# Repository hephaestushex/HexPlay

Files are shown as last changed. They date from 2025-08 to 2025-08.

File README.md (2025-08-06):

# HexPlay
A handheld gaming console powered by the Raspberry Pi 4/5. This handheld will run Android, using the touchscreen provided by the display. With 2 analog sticks and 15 more inputs, this will be able to play any game upto GameCube (using pi 5) or N64 (using pi 4). The handheld uses a powerbank to provide power to the handheld. This handheld is somewhat cold-swappable, with all connections to the pi is hdmi or usb.

I made this project for several reasons. Number one: points for flight reimbursement. Number two: my pi 4 was laying around, collecting dust. Number three: I've always loved playing retro games, especially those of the GameCube. I couldve made a simple handheld, with no analog joystick, but I found that unappealing because I wanted to play games with analog sticks. The HexPlay was born from there, going through many iterations, from a pcb handheld, an xbox style handheld, to the nintendo switch esque handheld that is here today. Overall, this project was a dream of mine ever since I got my pi, and its so nice to see it come into fruition 5 years later.







Uses GP2040-CE firmware - [link](https://gp2040-ce.info/)

# CAD

I have some M3x6 bolts and M3x5x4 heatset inserts left over from my keyboard, so I designed my case around them.

The joysticks are clamped in place with 4 posts, each with slots for m3 inserts.



The buttons will simply be inserted and hot glued. The button tops (the part the user presses) will simply be glued onto the tops of the buttons. This will work, so I submitted it early, but I'm designing a better system with an extrusion and hole for the button cap to fit into.



# Schematic



The schematic is just a wiring diagram, I am not using a PCB due to the components used. The display takes up most of the space, and the Pi is mounted behind it. Since I always intended to use an mcu as a bridge between the pi and the controls, there wasn't really a point to a pcb, as it would just complicate things (add one more thing to deal with in cad). Additionally, the joysticks would stick too far up from the controls if i were to mount it all on one flat plane. Another reason for not using a PCB is for the shoulder buttons. If I were to use shoulder buttons, I would need right angle buttons, which would increase the cost and complexity.



The connections from the Pi are pretty simple. The power bank plugs into the power socket, the mcu connects to a usb port, and the display connects to the pi via usb and microHDMI. Most connections are hidden behind a case, except for the powerbank connection. This is because I would like it to be cold-swappable, meaning I can just pop in a new power bank if the battery gets low.



The buttons are all individually wired. I didn't go with a matrix since it would add complexity (matrix, which would need a pcb, which I can't use because of components. Anyway, the RP2040 has more than enough GPIOs.



Here's an interesting part. The official Raspberry Pi Pico only exposes 3 ADC pins. The other ADC is tied to VSYS for power input sensing. The joysticks need 2 ADC pins each. Unfortunately, this means that I can't use a normal Pi Pico (or an orpheus pico for that matter) Luckily, other board expose all 4 ADC pins. One is the XIAO RP2040 and the other is the RP2040-Zero. The former doesnt have much pins (11 usable GPIOs) but the latter has more than enough. Anyway, the buttons are wired to some GPIOs.

# Software/Firmware

The RP2040-Zero runs GP2040-CE, a firmware that turns any RP2040 into a game controller. The firmware reads inputs from set pins, and outputs a signal to the pi with a less than 1ms latency. This is better than any custom firmware that I can make, plus, this firmware has been tried and tested by many people. As for the Pi, it will either run RetroPie or Android. Due to the nature of the controls and display, no other software needs to be written, as everything is plug and play. (Except for the display. The display will need some configuration options to work properly with the raspberry pi. But since this isn't firmware, im not counting it)

# BOM Notes

The two parts ordered off of Amazon are of same or less price than of aliexpress. Additionally, the power bank is from a reputable brand, so I don't burn my house down playing Zelda.

# BOM
| Name | Quantity  | Part Link | Description | Price (USD) |
|---|---|---|---|---|
| Raspberry Pi 4/5 | 1 | already owned | brains of the handheld | $55.00 |
| RP2040-Zero | 1 | [AliExpress](https://www.aliexpress.com/item/1005007650325892.html) | MCU for handling joystick and button input | $5.15 |
| Analog PS2 style Joystick | 2 | [AliExpress](https://www.aliexpress.com/item/1005007561985496.html) | Analog joystick for input | $1.69 |
| Soft Tactile Buttons | 15 | [AliExpress](https://www.aliexpress.com/item/32963848918.html) | button for input source | $1.81 |
| 7" Touchscreen Display with Speakers | 1 | [Amazon](https://www.amazon.ca/ELECROW-Raspberry-Touchscreen-1024x600-HDMI-Compatible/dp/B08FMNDDSL/) | touchscreen display with speakers | $47.49 |
| Equivalent AliExpress Display | 0 | [AliExpress](https://www.aliexpress.com/item/1005001315929149.html) | touchscreen display with speakers | $61.50 |
| 3D Printed Case and Buttons | 1 | already owned | custom case and buttons for the handheld | $4.00 |
| Wires | a lot | already owned | for connecting components | $1.00 |
| 10000mAh Power Bank | 1 | [Amazon](https://www.amazon.ca/INIU-Portable-Slimmest-10000mAh-Charging/dp/B0DCHVGS2S/) | Power bank for powering the device | $23.38 |
| Equivalent AliExpress Power Bank  | 0 | [AliExpress](https://www.aliexpress.com/item/1005008324698030.html) | powerbank. amazon also ships faster than ali for less | $36.67 |
| M3x6 Bolts | 14 | already owned | for securing components | $0.50 |
| M3x5x4 Heatset Inserts | 14 | already owned | for securing components | $0.50 |
|  |  |  | Total | $152.60 |
|  |  |  | Hack Club Total | $79.52 |

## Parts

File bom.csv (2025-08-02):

Name | Quantity | Part Link | Description | Price (USD)
Raspberry Pi 4/5 | 1 | already owned | brains of the handheld | $55
RP2040-Zero | 1 | https://www.aliexpress.com/item/1005007650325892.html | MCU for handling joystick and button input | $5.15
Analog PS2 style Joystick | 2 | https://www.aliexpress.com/item/1005007561985496.html | Analog joystick for input | $1.69
Soft Tactile Buttons | 15 | https://www.aliexpress.com/item/32963848918.html | button for input source | $1.81
7 inch Touchscreen Display with Speakers | 1 | https://www.amazon.ca/ELECROW-Raspberry-Touchscreen-1024x600-HDMI-Compatible/dp/B08FMNDDSL/ | touchscreen display with speakers | $59.57
Equivalent AliExpress Display | 0 | https://www.aliexpress.com/item/1005001315929149.html | touchscreen display with speakers | $61.50
3D Printed Case and Buttons | 1 | already owned | custom case and buttons for the handheld | $4
Wires | a lot | already owned | for connecting components | $1
10000mAh Power Bank | 1 | https://www.amazon.ca/INIU-Portable-Slimmest-10000mAh-Charging/dp/B0DCHVGS2S/ | Power bank for powering the device (device is cheaper than aliexpress) | $23.38
Equivalent AliExpress Power Bank | 0 | https://www.aliexpress.com/item/1005008324698030.html | powerbank. amazon also ships faster than ali for less | $36.67
M3x6 Bolts | 14 | already owned | for securing components | $0.50
M3x5x4 Heatset Inserts | 14 | already owned | for securing components | $0.50

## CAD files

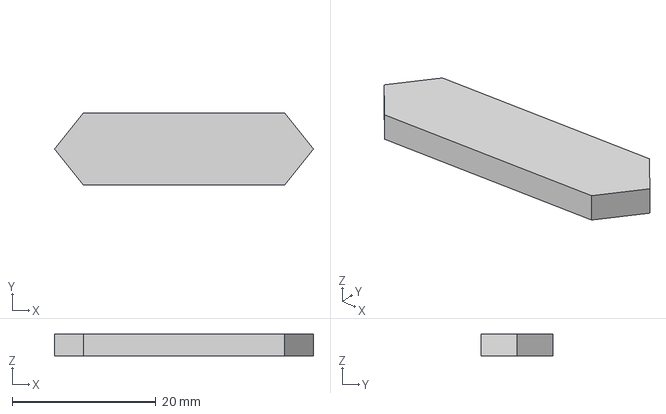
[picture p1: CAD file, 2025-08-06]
cad/start and select button.step
36.0 x 10.0 x 3.00 mm

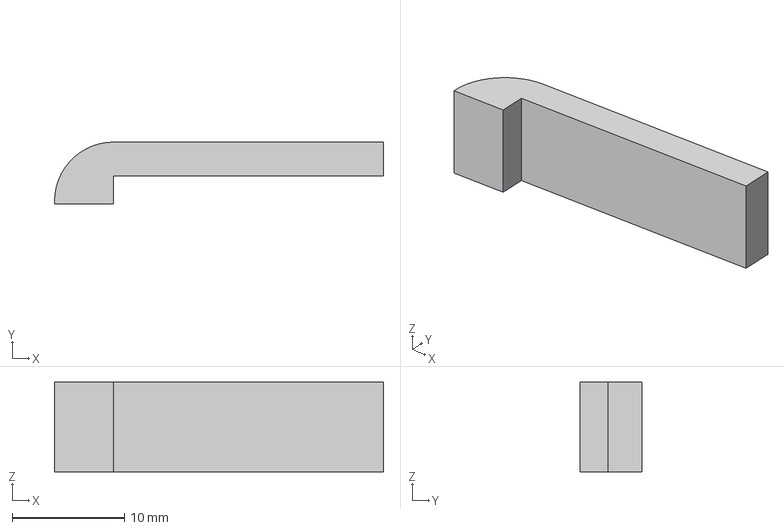
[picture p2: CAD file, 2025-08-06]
cad/shoulder button.step
29.3 x 5.50 x 8.00 mm

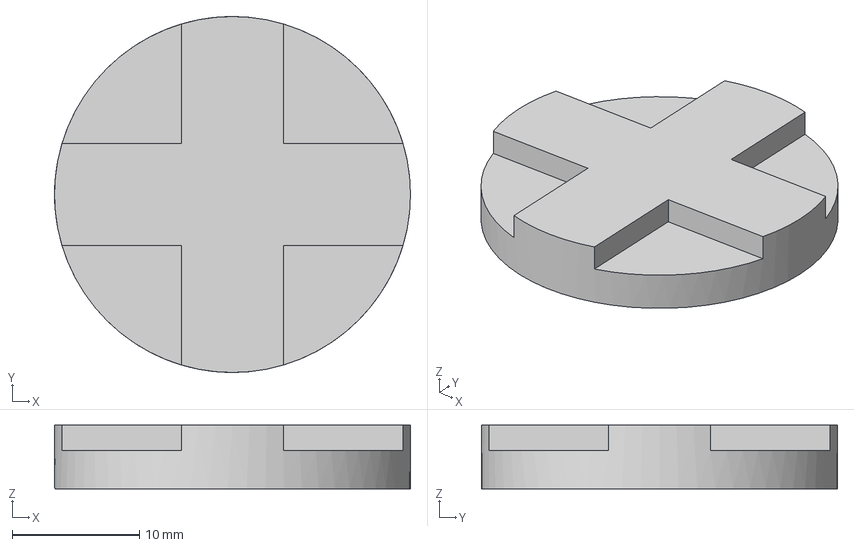
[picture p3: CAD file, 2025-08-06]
cad/dpad.step
28.0 x 28.0 x 5.00 mm

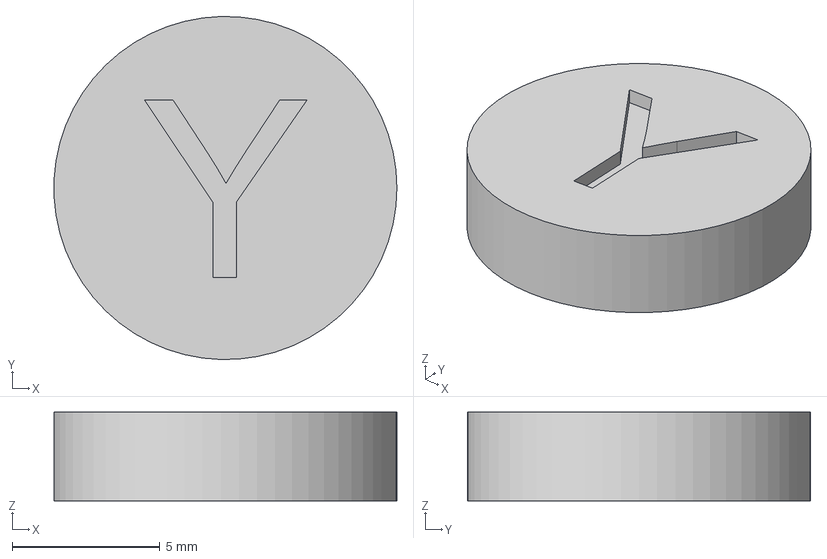
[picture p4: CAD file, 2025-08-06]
cad/y button.step
11.6 x 11.6 x 3.00 mm

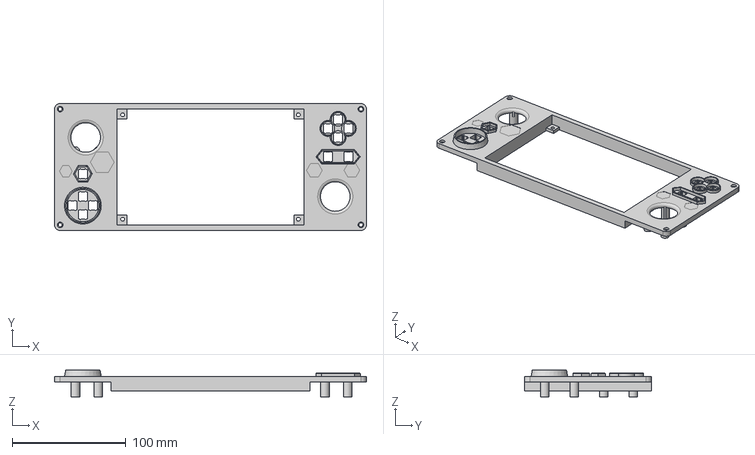
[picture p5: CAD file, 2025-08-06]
cad/Top Plate.step
274.9 x 112.0 x 23.4 mm

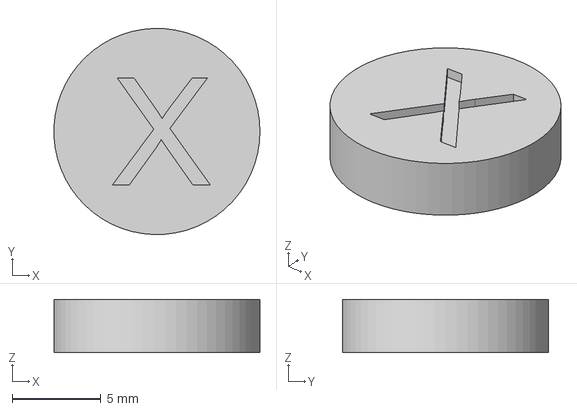
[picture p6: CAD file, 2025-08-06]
cad/x button.step
11.6 x 11.6 x 3.00 mm

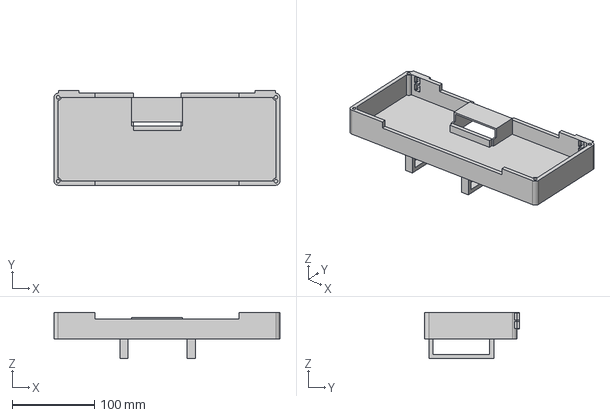
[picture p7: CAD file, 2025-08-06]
cad/Bottom plate.step
274.9 x 115.0 x 56.0 mm

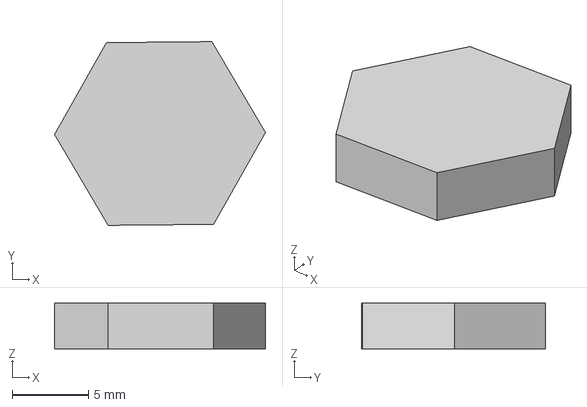
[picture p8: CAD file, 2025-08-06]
cad/home button.step
13.9 x 12.1 x 3.00 mm

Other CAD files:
cad/a button.step

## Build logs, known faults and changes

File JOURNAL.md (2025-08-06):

---
title: "HexPlay"
author: "hephaestushex"
description: "A handheld gaming console powered by the pi 4"
created_at: "2024-06-24"
---

# Total Time Spent: 16 Hours

# June 24th: Initial Planning

I initially wanted to make a retro gaming handheld with the pi zero 2w. I didn't like the idea of only being able to play retro games, so I decided to modify it to play any game. Since the pi zero 2w is underpowered, it would have to be replaced with a more powerful sbc. A pi 5 would be ideal, but since it would eat at my budget, I'm going to use a pi 4 4gb that I already own. This console should be able to play retro games, plus a few more, like minecraft. In this case, it is essential that the pi 4 is overclocked, but in order to not damage the pi, it would have to be cooled. Additionally, it would make sense for the display to be touchscreen, as a gaming controller wouldn't be an effective method of navigation.

With that initial brainstorm, a list of capabilities and things to do can be made.

Capabilities

- Play retro games
- Play modern games
- Touchscreen
- Easy to use controls
- Effective cooling

From there it would make sense to research components to use.

I liked [this](https://www.amazon.com/ELECROW-Raspberry-Monitor-Touchscreen-Capacitive/dp/B0CYKXCM8J?th=1) display used in a console designed by Leandro Linares over [here](https://leandrolinares.com/blog/diy-handheld-game-console/).

This display is only $38 USD, plus it handles audio/video plus touchscreen in one package.

As for controls, I want this to have a DPAD, A/B/X/Y buttons, L1/L2/R1/R2 Shoulder Buttons, 2x Analog Joysticks, start/select, and a hotkey button. More buttons may be added, but these were my bare minimums. Since the Pi does not have an ADC, I would need to use an external chip. In my use case, an external chip would be better.

For power management, I would like to have used the pisugar. Unfortunately, this would be too expensive, so I would have to use a lipo with a charging board.

I then took some time to create a few sketches to see what it would look like.

sketch

sketch_0001

With this out of the way, it was time to check out cooling. From my search, it seems like over clocking then cooling the pi is simply not worth it, so certain games will not be able to run, which is given, since this is a pi 4. I will simply stick to the heatsinks that came with my Pi.

Thats all the planning I did today

**Total time spent: 30mins**

# July 4th: tentative planning

11:23

I noticed that the repo didn't have hexplay on it, so I renamed it.

I don't think there is much to do, so I just decided to jump in by creating a schematic.

But firstly, I wanted to create a list of all the electronic components, grouped by function

## Electronic Components:

### Computer

- Raspberry Pi 4B x1

### Display

- ELECROW 5" Mini Touchscreen Display x1

### Controls

- 12mm Tactile Switch Buttons x11
- 12mm Tactile Switch Buttons Right Angle x4
- Analog Joystick x2
- MCP3008 - 8-Channel 10-Bit ADC With SPI Interface x1

### Audio

- Stereo 3.7W Class D Audio Amplifier MAX98306 x1
- Mono Enclosed Speaker with Plain Wires - 3W 4 Ohm x2

### Battery/Charging

- 18650 Li-ion Batteries x2
- Adafruit Powerboost 1000 Charger

**Total time spent: 1.5 hours**

# July 29th: Start actual design

I procrastinated alot, so I actually started today after a while. I didn't actually like the setup above, so I want to change it a little. After a good 1 and a half hours to talking to ChatGPT and some research on GP2040-CE, here's my setup. What influenced this is the fact that Jumpstart exists, and building a similar level of emulation is pointless. I want this to be better. Here's the final setup, all using HDMI cables and USB Cables. Also, this setup will be able to switch computers easily, as in, I'll use my pi 4 to run it, and after getting a pi 5, use that instead. The setup will also be powered by a powerbank, as the 18650 cells I have do not deliver enough power 5V/5A - 25W. My two batteries combined have 14.8 Wh. That's even less than one hour runtime on the Pi 4 (15W). I could get a lipo, but that still causes the issue of charging and discharging. Most of the solutions nowadays aren't great. So, heres the final setup.

### Display and Audio

I upgraded to the 7 inch version of the display for two reasons. 
A: the display is bigger, making 3d games a lot more playable
B: Built in speakers make this project a whole lot more simpler.

[link to display](https://www.amazon.com/ELECROW-Raspberry-Touchscreen-Capacitive-1024x600/dp/B08FMNDDSL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)

After looking around, this display seems pretty good.

### Computer

I plan on using my pi 4, and upgrading to the pi 5 which I plan to get from Summer of Making. As for cooling, the active cooler is pretty cheap at $7 CAD, which I can pay out of pocket later. 

### Controls

As for the controls, the seeed xiao rp2040 has 4 analog pins. I can put the buttons in a matrix for the other buttons.

The xiao has 11 usable GPIOs, with 4 being taken for analog input. That leaves us with a 7 remaining pins. that leaves us with 12 buttons. I need 17. 

That won't work. I have an adc, plus a orpheus pico. I could connect the adc for analog input use the other pins for switches. Phew. that will work.

As for the joysticks, I'll buy some joysticks you'd find in an arduino kit.

### Power

This is simple. Buy a power bank and use that to power the pi. 

### Case

This will be 3d printed

### Mounting

As I'm very close to the deadline, a pcb is unfeasible. This is ok anyway, as a PCB is hard, since that would constrain elements to a set height, plus the joysticks that are the most simple wouldn't mount to a pcb anyway.

What i'll most likely do is design holes on the case for some simply tactile pushbuttons to mount to, and I'll hot glue in the buttons, and solder wires from the legs to the pico. This setup is simple, and is way cheaper than making a pcb.

That's all i did today.

**Total time spent: 3h**

# July 30th: Schematic Speedrun

Time for a speedrun!

With the specs set above, this is what I got in terms of controls



Looks like after looking at what Highway wants, i need to create a diagram for all the wiring. After messing around in other editors, I just created some custom symbols in KiCAD and ended up with this as my image.



After this, its just CAD and some code for the pi.

It's pretty late for me so thats it for today

**Total time spent: 1h**

# July 31st: Everything Speedrun

After procrastinating some more, I started filling out the BOM.



All was fine until the powerbank. I spent so long on this for two simple reasons. The Pi 5 needs 5V/5A to run accessories. most powerbanks only have 5v/3a. I spent so long looking for a solution, with lipos, liions, tp4056 modules, buck/boost converters. In the end i found a power bank that offered 5V/3A over two ports to power the display if needed. A bonus of this powerbank is that it already has a usb-c cable built in, making the amount of cables one less.

Also while doing this, I realized that the ADC I have has pins soldered to it, plus I wanted to find a jank free setup. The Waveshare RP2040 zero solves this, but the only problem is that I would have to order this off of ali, which might delay the build process. As of writing this, I realized I can remove the headers. But, the adc is 8 bit (0-255) compared to the pico's 12 bit (1-4095). Anyway, I'll buy three things off of ali, the rp2040 zero, the joysticks, and some squishy buttons. The only issue with using the rp4040 zero is that I have to connect one button to a pad on the back, but thats better than using another chip with less accuracy. From here, I just have to make a table version of the bom, and cad up a design. In the last entry i mentioned making a custom firmware, but I found out about gp2040-ce, which makes controller firmware not only easy, but buttery smooth with a less than 1 ms latency.

With all that done, i hopped on fusion to design a case.

First step was to get the dimensions and get modelling. One interesting thing I did was use snipping tool to take a picture of the display to find the dimensions of the display, based off of a hdmi connector. As for mounting the display and joystick, i just inseted four corners and made a hole. After all of that, this is what I got



its 5 mins to the deadline, so let me submit.

ok so after submitting i polished up the design, added a hole for the pi's power and audio, and a holder for the power bank







I also designed a button to put on top of the squishy buttons. So I think thats it, lemme look at the requirements. 

From there I just finished the few things I didnt have and filled out the re-review form

**Total time spent: 10h**

# August 5th: Case Polishing

Here is the initial case I submitted:



I felt like this wouldn't meet the level of polishing wanted by the reviewers, so I hopped on fusion and started designing.

The first thing I made is this DPAD





Here I developed a method for all my buttons. I made the outline of the button, aligned to the tactile button cutouts. Then, I used the offset tool to make 2 offset perimeters. One, 0.2mm away from the original button, for tolerances, and another 1 mm away from the second offset, for the button housing. With this method I was able to create the other buttons,

### Home Button





### Start and Select





For this button, I did something similar to the d pad and made a large button, able to move up and down and two spots. 

### Face Buttons



I embossed the letters on the face. I chose nintendo style layout, since I plan on playing nintendo games.

Here I merged the walls, so it would fit.

### Shoulder Buttons



I expanded the button length for easier pressing, and curved the edge to fit with the design.

### Joystick



Previously I just stuck it to the top of the case and called it, but that didnt feel right. I did a previous project a few years ago with the same joystick, so I took the dimensions used and made better joystick. On the previous project, the dimension of the top plate was 3mm thick, but this case plate is 5mm thick. To fix that, I just filleted the edges.

Finally, I added some material to make the port sides look cleaner.



**Total time spent: 3h**

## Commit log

2025-08-01 add updated schematics and bom
    [bom.csv, hexplay.kicad_pcb, hexplay.kicad_sch]
2025-08-01 Update README.md to add bom
2025-08-01 added cad files
    [Bottom Shell.step, Top Shell.step]
2025-08-01 updated cad files
    [Bottom Shell.step, Top Plate.step, Top Shell.step]
2025-08-01 added finalized cad files
    [hexplay.kicad_sch]
2025-08-06 added updated step files
    [Bottom Shell.step, Bottom plate.step, Top Plate.step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]
